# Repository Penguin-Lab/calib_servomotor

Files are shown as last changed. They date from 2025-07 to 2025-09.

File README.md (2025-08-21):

# calib_servomotor
Esse é o calibrador automático de motores servo desenvolvido para agilizar a vida do desenvolvedor de robôs a patas!

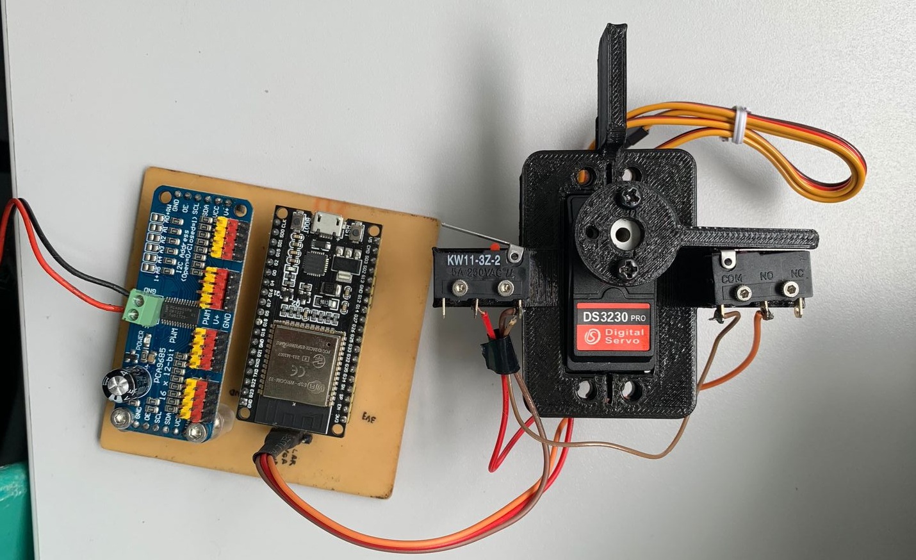
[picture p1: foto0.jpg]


## Modo de uso:
Para testar o sistema, o usuário deve:
- Conectar a ESP32 no computador e o motor na PCA9685
- Ligar o sistema com a bateria e pressionar as setas do Game Pad de forma a mexer o eixo do motor e descobrir de forma vaga valores mínimo e máximo de PWM que o motor aceita
- Posicionar de forma vaga o eixo do motor ao centro dessa faixa
- Fixar o motor na estrutura base
- Encaixar o disco no eixo do motor e apeça do ponteiro no disco
- Pressionar o botão quadrado e esperar até que o ponteiro pare na chave fim de curso
- Pressionar o botão círculo e esperar até que o ponteiro pare na chave fim de curso
- Pressionar a cruz para confirmar que o eixo se move para a marcação de centro (0 graus)
- Pressionar o triângulo para escrever no Monitor Serial da IDE do Arduino a faixa de valores para -90 e +90 graus
- Colocar a faixa estimada no arquivo Excel, que retorna a faixa PWM para 0 e 180 graus
- Com o disco posicionado na posição 0 graus, pode-se retirar o motor do sistema e conecta-lo na pata do robô a ser construído

## Aluno participante e desenvolvedor do calibrador automático de servo motor
- Samuel Gurgel Rocha

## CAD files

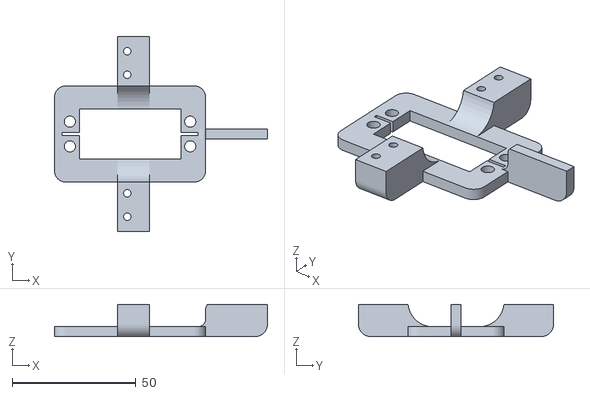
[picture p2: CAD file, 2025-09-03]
Pecas_3d/CALIB_MOTOR_BASE.STL
86.0 x 78.8 x 13.0

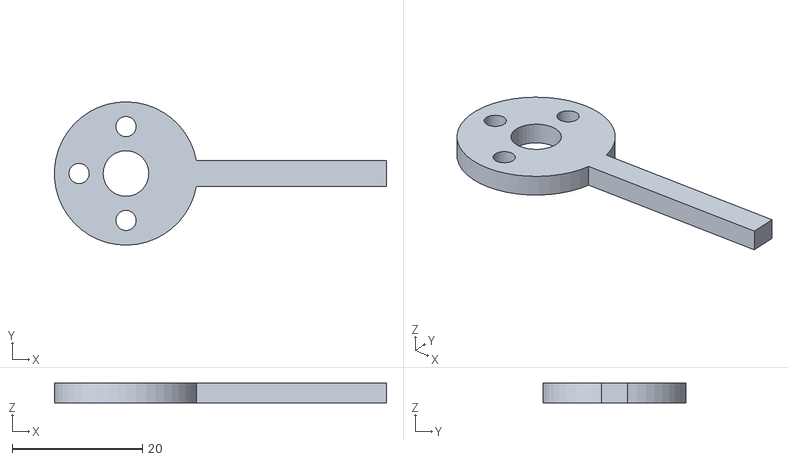
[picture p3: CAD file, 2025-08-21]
Pecas_3d/CALIB_MOTOR_PINO.STL
51.0 x 22.0 x 3.00

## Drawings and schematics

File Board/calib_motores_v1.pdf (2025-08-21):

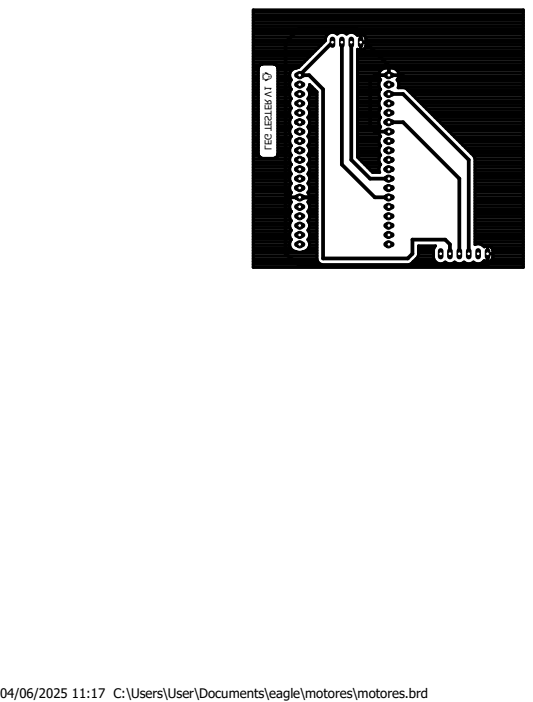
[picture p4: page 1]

04/06/2025 11:17 C:\Users\User\Documents\eagle\motores\motores.brd LEG TESTER V1

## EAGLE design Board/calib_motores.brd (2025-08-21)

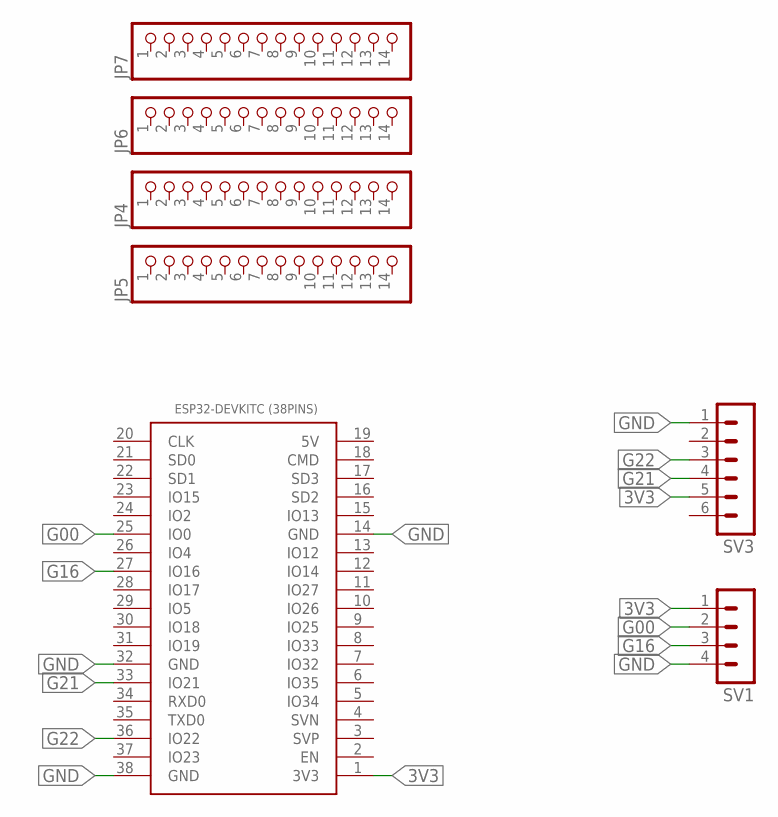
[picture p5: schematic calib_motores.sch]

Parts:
ESP32-DEVKITC(38PINS)1: ESP32DEVKITC_38PINS; ESP32-DEVKITC
JP4, JP5, JP6, JP7: PINHD-1X14; 1X14
SV1: MA04-1
SV3: MA06-1

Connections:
3V3: ESP32-DEVKITC(38PINS)1.1 (3V3), SV1.1, SV3.5
G00: ESP32-DEVKITC(38PINS)1.25 (IO0), SV1.2
G16: ESP32-DEVKITC(38PINS)1.27 (IO16), SV1.3
G21: ESP32-DEVKITC(38PINS)1.33 (IO21), SV3.4
G22: ESP32-DEVKITC(38PINS)1.36 (IO22), SV3.3
GND: ESP32-DEVKITC(38PINS)1.14 (GND), ESP32-DEVKITC(38PINS)1.32 (GND), ESP32-DEVKITC(38PINS)1.38 (GND), SV1.4, SV3.1

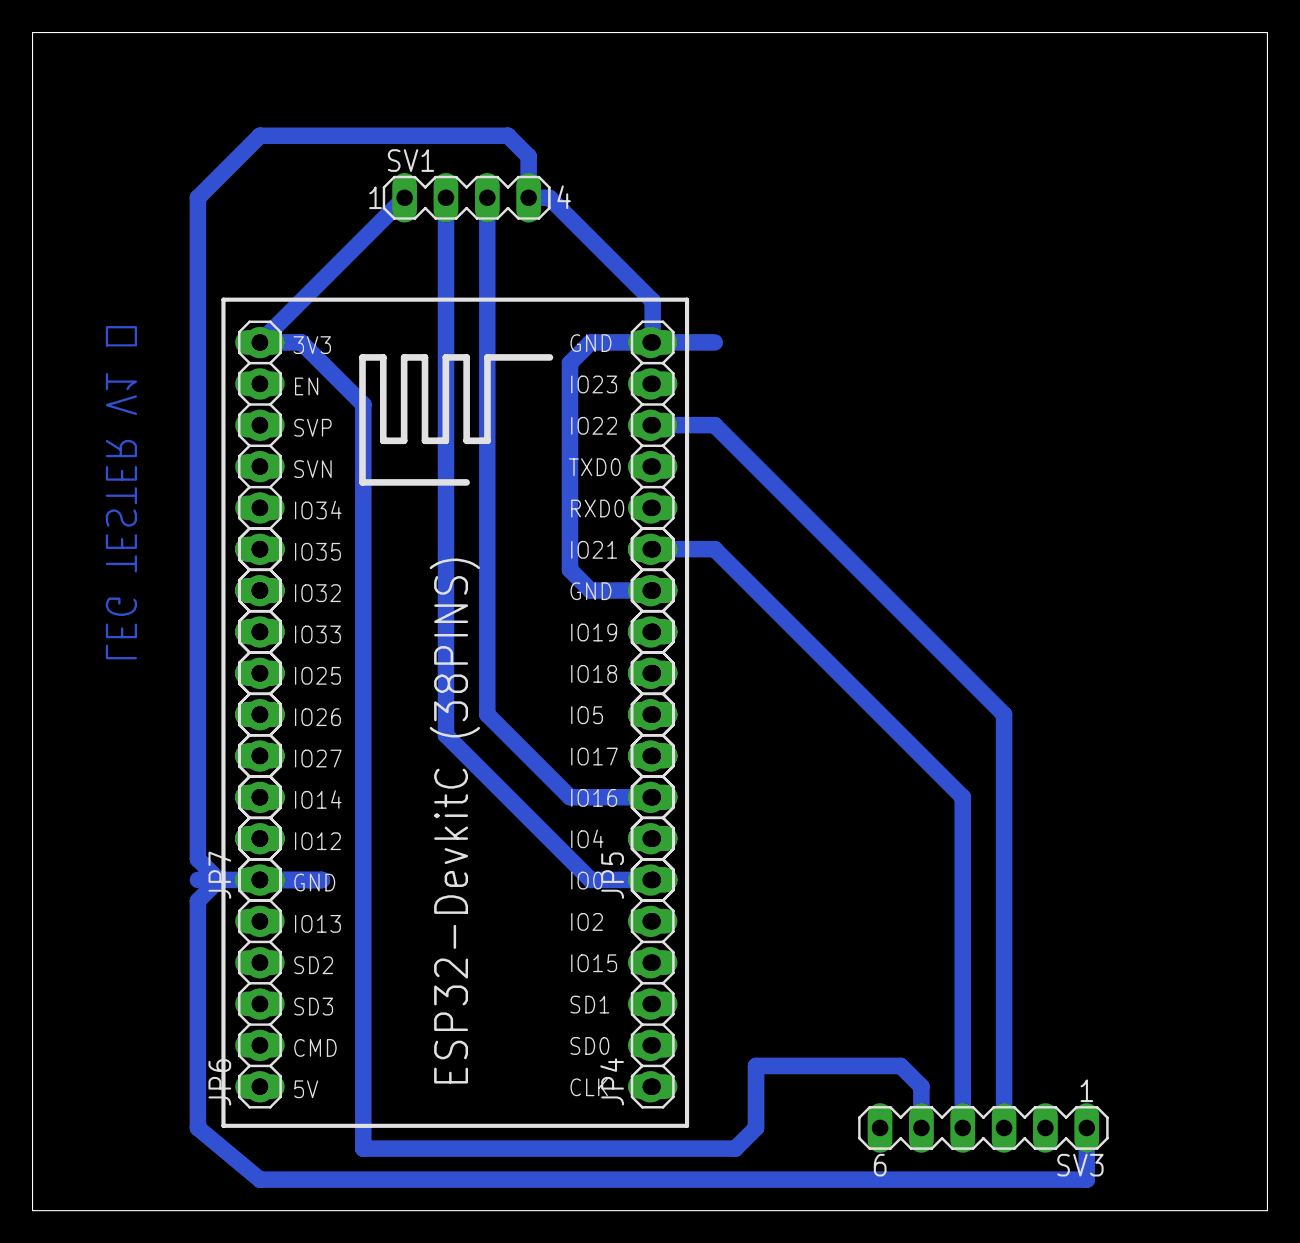
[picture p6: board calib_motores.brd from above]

Board: 2 copper layers, 75.9 x 72.4 mm, 7 parts (0 on the bottom side), 6 nets.

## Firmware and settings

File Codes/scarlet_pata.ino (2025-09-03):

#define CUSTOM_SETTINGS
#define INCLUDE_GAMEPAD_MODULE
#include <DabbleESP32.h>
#include <Wire.h>
#include <Adafruit_PWMServoDriver.h>

Adafruit_PWMServoDriver pwm = Adafruit_PWMServoDriver();

struct Pata {
  Adafruit_PWMServoDriver* pwm;
  int pinOmbro;
  int pinFemur;
  int pinTibia;
  int angOmbro;
  int angFemur;
  int angTibia;
  float angOmbro_rad;
  float angFemur_rad;
  float angTibia_rad;
  int OMIN;
  int OMAX;
  int FMIN;
  int FMAX;
  int TMIN;
  int TMAX;

  Pata(Adafruit_PWMServoDriver* pwm, int pinOmbro, int pinFemur, int pinTibia, int OMIN, int OMAX, int FMIN, int FMAX, int TMIN, int TMAX) {
    this->pwm = pwm;
    this->pinOmbro = pinOmbro;
    this->pinFemur = pinFemur;
    this->pinTibia = pinTibia;
    this->angOmbro = -1;
    this->angFemur = -1;
    this->angTibia = -1;
    this->OMIN = OMIN;
    this->OMAX = OMAX;
    this->FMIN = FMIN;
    this->FMAX = FMAX;
    this->TMIN = TMIN;
    this->TMAX = TMAX;
  }
  
  void moverPata(int angOmbro, int angFemur, int angTibia) {
    if (this->angOmbro != angOmbro) {
      this->angOmbro = angOmbro;
      int pulso = map(this->angOmbro, 0, 180, OMIN, OMAX);
      pwm->setPWM(this->pinOmbro, 0, pulso);
    }
    if (this->angFemur != angFemur) {
      this->angFemur = angFemur;
      int pulso = map(this->angFemur, 0, 180, FMIN, FMAX);
      pwm->setPWM(this->pinFemur, 0, pulso);
    }
    if (this->angTibia != angTibia) {
      this->angTibia = angTibia;
      int pulso = map(this->angTibia, 0, 180, TMIN, TMAX);
      pwm->setPWM(this->pinTibia, 0, pulso);
    }
    Serial.print("Ombro " + String(this->angOmbro));
    Serial.print(" Femur " + String(this->angFemur));
    Serial.println(" Tibia " + String(this->angTibia));
  }
};

int angOmbro = 0;
int angFemur = 0;
int angTibia = 0;

// Pata EsqF = {&pwm, 0, 1, 2, 292, 718, 306, 727, 135, -298};
Pata EsqF = {&pwm, 0, 1, 2, 292, 718, 306, 727, 141, -277};

void setup() {
  Serial.begin(115200);
  Dabble.begin("Pata");
  Serial.println("Teste de pata!");

  pwm.begin();
  pwm.setPWMFreq(50);

  delay(2000);

}

bool cima = 0;
bool baixo = 0;
void loop(){
  Dabble.processInput();
  if (GamePad.isUpPressed()){
    EsqF.moverPata(angOmbro,angFemur,angTibia);
  }

  if (GamePad.isLeftPressed()){
    EsqF.moverPata(45,45,-45);
  }
  
  delay(200);
}

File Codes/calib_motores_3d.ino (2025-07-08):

#define CUSTOM_SETTINGS
#define INCLUDE_GAMEPAD_MODULE
#include <DabbleESP32.h>
#include <Wire.h>
#include <Adafruit_PWMServoDriver.h>

Adafruit_PWMServoDriver pwm = Adafruit_PWMServoDriver();
int PULSO_MIN = 100;
int PULSO_MAX = 540;
int pulso = (PULSO_MAX-PULSO_MIN)/2;
int passinho = 5;
#define TEMPO 10


void setup() {
  Serial.begin(115200);
  Dabble.begin("Motor");
  Serial.println("Calibração de motores!");
  pinMode(0,INPUT_PULLUP);
  pinMode(16,INPUT_PULLUP);

  pwm.begin();
  pwm.setPWMFreq(50);  // This is the maximum PWM frequency

  pwm.setPWM(0, 0, pulso);
  Serial.println("Pulso: " + String(pulso));
  delay(2000);

}

bool cima = 0;
bool baixo = 0;
void loop(){
  // Serial.print(digitalRead(0));
  // Serial.println(digitalRead(16));
  Dabble.processInput();
  if (GamePad.isUpPressed()&&!cima){
    pulso+=passinho;
    pwm.setPWM(0, 0, pulso);
    Serial.println("Pulso: " + String(pulso));
    cima = !cima;
  }

  if (GamePad.isRightPressed()&&cima){
    pulso+=passinho;
    pwm.setPWM(0, 0, pulso);
    Serial.println("Pulso: " + String(pulso));
    cima = !cima;
  }

  if (GamePad.isDownPressed()&&!baixo){
    pulso-=passinho;
    pwm.setPWM(0, 0, pulso);
    Serial.println("Pulso: " + String(pulso));
    baixo = !baixo;
  }

  if (GamePad.isLeftPressed()&&baixo){
    pulso-=passinho;
    pwm.setPWM(0, 0, pulso);
    Serial.println("Pulso: " + String(pulso));
    baixo = !baixo;
  }

  if (GamePad.isSquarePressed()){
    while(true){
      pulso++;
      pwm.setPWM(0, 0, pulso);
      Serial.println("Pulso: " + String(pulso));
      delay(TEMPO);
      if (!digitalRead(16)){
        break;
      }
    }
    pulso-=2;
    pwm.setPWM(0, 0, pulso);
    PULSO_MAX = pulso;
    Serial.println("Pulso máximo: " + String(PULSO_MAX));
  }
  if (GamePad.isCirclePressed()){
    while(true){
      pulso--;
      pwm.setPWM(0, 0, pulso);
      Serial.println("Pulso: " + String(pulso));
      delay(TEMPO);
      if (!digitalRead(0)){
        break;
      }
    }
    pulso+=2;
    pwm.setPWM(0, 0, pulso);
    PULSO_MIN = pulso;
    Serial.println("Pulso minimo: " + String(PULSO_MIN));
  }
  if (GamePad.isTrianglePressed()){
    Serial.println("Faixa: " + String(PULSO_MIN) + " a " + String(PULSO_MAX));
  }
  if (GamePad.isCrossPressed()){
    pulso = int((PULSO_MAX+PULSO_MIN)/2);
    pwm.setPWM(0, 0, pulso);
    Serial.println("Valor: " + String(pulso));
  }
  delay(200);
}
